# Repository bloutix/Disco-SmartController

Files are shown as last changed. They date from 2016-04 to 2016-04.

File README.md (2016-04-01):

# Disco-SmartController
Arduino based Smart Controller for Dagoma Discovery 200 or Melzi printer with Marlin fw

Version: 1.0b

Prérequis:
	- Arduino MEGA 2560
	- 3.2 " TFT touch
	- TFT LCD MEGA Shield V1.0
	- Un adaptateur BT HC-06 (optionnel)
	- Flash IC (sera une option) mais ne peux fonctionner sans si aucune modification dans le code
	- des cables Dupont

Le contenu du fichier Libraries.zip est à copier dans le dossier librarie de l'ide ARDUINO.

Il vous faut changer le port série dans le fichier configuration du firmware Marlin en SERIAL1.
Attention: le fait de changer le port série empêche de controller l'imprimante depuis l'USB de la Melzi,
mais le controle est possible via l'USB de l'Arduino (115200 bps).

Connection du Smart Controller vers la MELZI:
	- RX (melzi) -> TX1 (Arduino)
	- TX (melzi) -> RX1 (Arduino)
	- GND (melzi) -> GND (Arduino)
	
Connextion du module Bluetooth:
	- RX (BT) -> TX2 (Arduino)
	- TX (BT) -> RX2 (Arduino)
	- GND (BT) -> GND (Arduino)
	- VCC (BT) -> 5V

Les fonctionnalités:
	- Affichage de la température (Hotend + Bed)
	- Réglages température, pas de déplacement (0.1, 1, 10, 100mm)
	- Mise en Pause de l'impression
	- Arret d'urgence
	- Connextion Switch (Controller->Melzi, BT->Melzi, USB->Melzi)
	- Déplacement manuel des axes, Homing, filament
	- Marche / Arrêt du ventilateur
	- Control d'un ou plusieurs SERVO (à améliorer)
	
  Fonctionnalités à venir:
	- Affichage et sélection d'un fichier à imprimer sur la SD
	- Affichage du temps restant, et numéro de couche en cours
	- Envoi manuel de G-code, M-code
	- Réglage du SmartController depuis l'écran (variables, diverses et activation/désactivation de fonctionnalités)
	
Attention!!!
	Le SmartController est en cours de développement et je ne pourrai en aucun cas être tenu responsable d'une mauvaise utilisation,
	ou de la présence de bug indésirable.

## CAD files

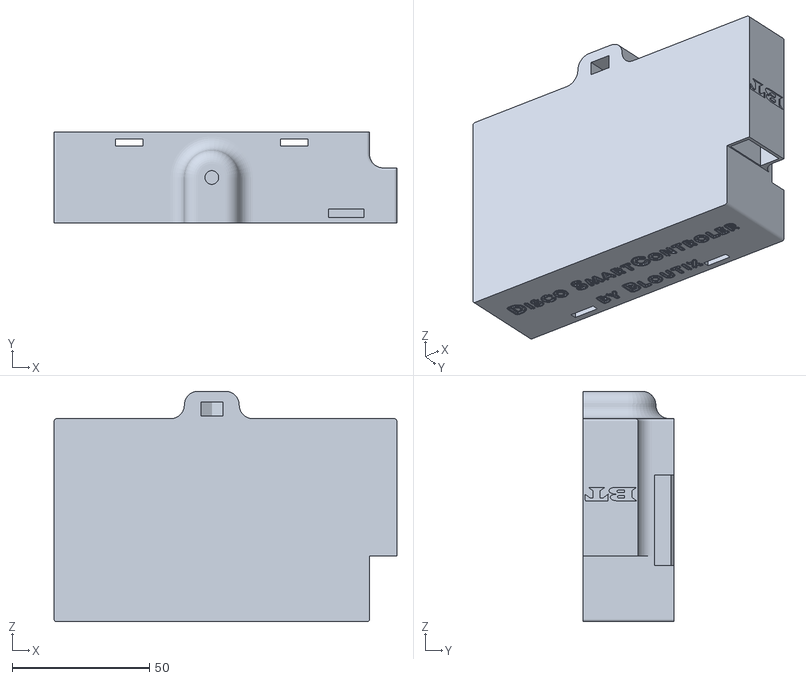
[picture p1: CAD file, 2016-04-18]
STL/Smart Controller Case.STL
125.0 x 33.0 x 84.0

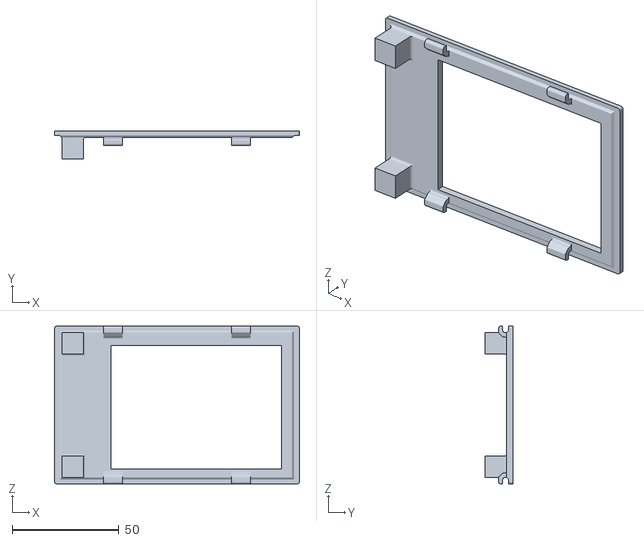
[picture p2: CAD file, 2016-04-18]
STL/Smart Controller Top.STL
115.0 x 13.0 x 74.0

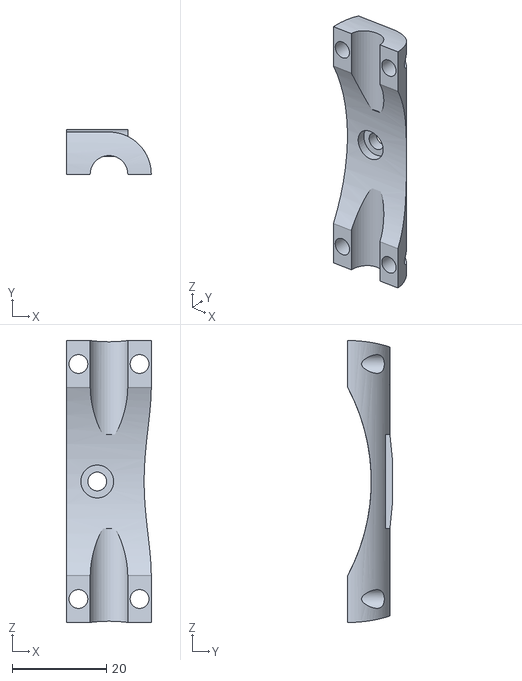
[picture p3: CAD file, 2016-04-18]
STL/mount_top.STL
18.0 x 9.50 x 60.0

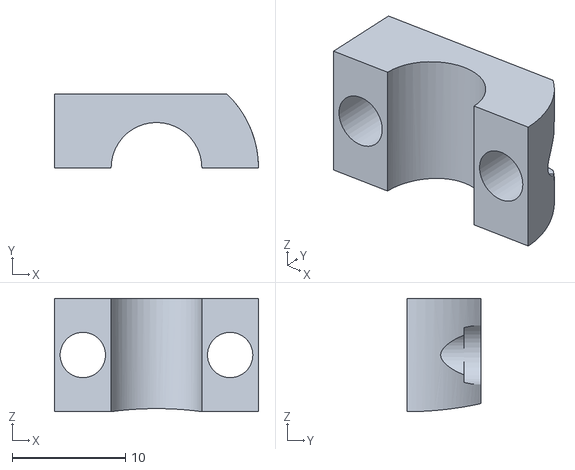
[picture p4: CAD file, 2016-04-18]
STL/mount_bottom.STL
18.0 x 6.50 x 10.0

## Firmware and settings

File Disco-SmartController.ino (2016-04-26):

/*  Disco-SmartController by Bloutix <bloutix@hotmail.fr>
 *   This program is in developement and it was created for Dagoma Discovery 200
 *   
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
 *  Version: 1.0b
 *  Hardware: 
 *  - Arduino MEGA2560, TFT 320QVT or other 3.2 tft touch screen 320x240
 *  - TFT LCD Mega Shield V1.0 moded (added SPI flash memory wire) (will be optionnal)
 *  - Winbond SPI flash IC for storing 
 *  - Bt device: HC-06
 *  - some wire
 */

#include "Arduino.h"
#include <avr/pgmspace.h>
#include <EEPROM.h>

#include <UTFT.h>
#include <UTouch.h>
#include <TFT_ExtensionV2.h>
#include <SPI.h>
#include <SPIflash.h>
#include <UTFT_SPIflash.h>

#include "variables.h" //loading variable setting
#include "FWcode.h"   //gcode command
#include "language.h" //language array

//this is for servo z-probe
/*#include <Servo.h>
Servo Zservo;*/
//bool zstate = false;
void setup(){ 
    //Dont Touch this
  for(int i=0;i<8;i++){  //it take config from EEPROM
    addr[i]=EEPROM.read(i);
    delay(5);
  }
  //Dont touch this
  SERIAL_P.begin(spdVal(addr[0]>>5)); //init printer com dont delete
  SERIAL_U.begin(spdVal(addr[0]>>5));
  SERIAL_P.setTimeout(100);
  SERIAL_U.setTimeout(100);
  
  myFlash.begin();  //images stored in lcd flash ic
 // Zservo.attach(9);
  
  myGLCD.InitLCD();
  myGLCD.clrScr();
  myGLCD.setFont(SmallFont);
  myTouch.InitTouch();
  myTouch.setPrecision(PREC_MEDIUM);

  TCHB.Coords(20,60,68,108);
  BTB.Coords(90,60,138,108);
  USBB.Coords(20,130,68,178);
  SETB.Coords(90,130,138,178);
  TCHB.Colors(GREEN,WHITE,NOFILL,SQUARED);
  BTB.Colors(GREEN,WHITE,NOFILL,SQUARED);
  USBB.Colors(GREEN,WHITE,NOFILL,SQUARED);
  SETB.Colors(GREEN,WHITE,NOFILL,SQUARED);
  BACK.Coords(0,220,20,239);
  BACK.Colors(GREEN,BLACK,NOFILL,SQUARED);
  myGLCD.fillScr(BLACK);
}

void loop() { 
  switch(disp_pg){
    case 0:
      disp_HOM();
    break;
    case 1:
      disp_TCH();
    break;
    case 2:
      disp_BT();
    break;
    case 3:
      disp_USB();
    break;
    case 4:
      disp_SET();
    break;
    case 5:
      disp_SD();
    break;
    case 6:
      disp_Mcode();
    break;
  }
}  
/*void serialEvent(){
  if(!autoUSB){
    loaded = false;
    myGLCD.setColor(BLACK);
    myGLCD.fillRect(0,10,319,239);
    autoUSB = true;
    disp_pg=3;
  }
}
/*void serialEvent1(){
    chkServo();
}
void serialEvent2(){
 if(!autoBT && bitRead(addr[0],1)){
    loaded = false;
    myGLCD.setColor(BLACK);
    myGLCD.fillRect(0,10,319,239);
    autoBT = true;
    disp_pg=2;
 }
}*/
//PAGES d'affichage
void disp_Mcode(){    //afichage du clavier pour envoie de ligne de commande
  if (loaded == false) {
    myGLCD.setColor(BLACK);
    myGLCD.fillRect(0,10,319,220);
    myFiles.loadBitmap(5,0,219);
    myGLCD.setBackColor(BLACK);
    myGLCD.setColor(RED);
    myGLCD.print(str(0),CENTER,15);
    myKB.Colors(WHITE, BLACK, GREY, NOFILL);
    myKB.SetupMobileKB(0,30, 319, 180); //NEEDED TO WORK!
    loaded = true;
  }
  char buf[30] = {'\0'};
  myKB.ReceiveMsg(20, 225, WHITE); // X,Y(position on screen), Color
  if (myKB.Mobile_KeyBoard(buf, BLUE))
  {
    setStateDisplay(buf);
    SERIAL_P.println(buf);
    /*awaitingOK=true;
    while(awaitingOK){
      //checkForOk();
    }*/
  }
  if (BACK.Touch()){
    myGLCD.setColor(BLACK);
    myGLCD.fillRect(0,10,319,239);
    disp_pg =1;
    loaded = false;
  }
}
void disp_HOM(){  //affichage de l'écran d'accueil
  if (loaded == false) {
  myGLCD.setColor(CYAN);
  myGLCD.drawRoundRect(0,224,319,239);
  myGLCD.setColor(BLACK);
  myGLCD.fillRect(0,0,319,10);
  myGLCD.setBackColor(BLACK);
  myGLCD.setColor(CYAN);
  myGLCD.print(str(1),CENTER,0);
  myGLCD.setColor(CYAN);
  myGLCD.print(str(2),CENTER,225);
  BTB.ReDraw();
  TCHB.ReDraw();
  USBB.ReDraw();
  SETB.ReDraw();
  myFiles.loadBitmap(4,160,45); //logo dagoma
  myFiles.loadBitmap(6,90,130); //logo setting
  myFiles.loadBitmap(7,90,60);  //logo usb
  if(bitRead(addr[0],1)){
     myFiles.loadBitmap(8,20,130); //logo bluetooth
  }
  myFiles.loadBitmap(9,20,60);  //logo touchinterface
  loaded = true;
  }

  if (TCHB.Touch()){
    loaded = false;
    myGLCD.setColor(BLACK);
    myGLCD.fillRect(0,10,319,239);
    disp_pg = 1;
  } else if(BTB.Touch() && bitRead(addr[0],1)){
    if(bitRead(addr[0],1)){
      loaded = false;
      myGLCD.setColor(BLACK);
      myGLCD.fillRect(0,10,319,239);
      disp_pg = 2;
    }
  } else if(USBB.Touch()){
    loaded = false;
    myGLCD.setColor(BLACK);
    myGLCD.fillRect(0,10,319,239);
    disp_pg = 3;
  } else if(SETB.Touch()){
    loaded = false;
    myGLCD.setColor(BLACK);
    myGLCD.fillRect(0,10,319,239);
    disp_pg = 4;
  }
}
void disp_TCH(){  //affichage de l'interface de controle tactil
  if (loaded == false) {
  #include "interface.h" //loading customised interface var and function
  myFiles.loadBitmap(5,0,219);
  moveS.Unlock();
  tempB.Unlock();
  tempH.Unlock();
  Print_Bar.Unlock();
  moveS.SetStartingValue(lastMv);
  tempB.SetStartingValue(lastTb);
  tempH.SetStartingValue(lastHb);
  moveS.Draw();
  tempB.Draw();
  tempH.Draw();
  Print_Bar.Draw();
  loaded = true;
  }
    
  InitTouchInterface();
  unsigned long currentMillis = millis();
  if (Bst.Touch()){  //arret urgence
     sendGcode(code(10)); //10->M112 or 11->M410
  }
    if ((currentMillis - lastUpdate) >= 5000) { //affiche la température toute les 5 secondes
      getTemperatures();
      getPrintState();
      lastUpdate=currentMillis; 
    }
  if (BACK.Touch()){
    myGLCD.setBackColor(BLACK);
    myGLCD.setColor(BLACK);
    myGLCD.fillRect(0,10,319,239);
    myGLCD.fillRect(0,0,15,10);
    disp_pg =0;
    loaded = false;
  }
}
void disp_SET(){  //affichage de la fenetre de parametrage
  if (loaded == false) {
        myGLCD.setColor(BLACK);
        myGLCD.fillRect(0,10,319,239);
        myGLCD.setBackColor(BLACK);
        myGLCD.setColor(RED);
        myGLCD.print(str(0),CENTER,15);
        SDPTB.Coords(245,220,319,239);
        SDPTB.Colors(BLACK,FILL,SQUARED);
        myFiles.loadBitmap(5,0,219);//back btn
        sub_loaded = false;
        loaded = true;
      }
  switch (sub_pg){
    case 0: //pge lanques, bt, bed, dago, flash ic
      if (sub_loaded == false) {
          rstBtn(0);
          myGLCD.setColor(WHITE);
          myGLCD.print(str(4),20,40);
          myGLCD.print(str(5),120,40);
          myGLCD.print(str(6),170,40);
          myGLCD.print(str(7),20,70);
          myGLCD.print(str(8),20,100);
          myGLCD.print(str(9),20,130);
          myGLCD.print(str(10),20,160);
        sub_loaded = true;
      }
        myRB.RadioButtons(Chkbox);
        Bt3.Toggle();
        Bt4.Toggle();
        Bt5.Toggle();
        Bt6.Toggle();
        if(SDPTB.Touch()){
          bitWrite(addr[0],0,((Bt1.getState()) ? 0 : 1)); //langue FR/EN
          bitWrite(addr[0],4,((Bt3.getState()) ? 1 : 0)); //Marlin FW Dagoma / !Dagoma
          bitWrite(addr[0],1,((Bt4.getState()) ? 1 : 0)); //Bluetooth
          bitWrite(addr[0],2,((Bt5.getState()) ? 1 : 0)); //BED
          bitWrite(addr[0],3,((Bt6.getState()) ? 1 : 0)); //Flash IC 
        
          myGLCD.setColor(BLACK);
          myGLCD.fillRect(0,30,319,219);
          sub_pg = 1;
          sub_loaded = false;
        } else if (BACK.Touch()){
          myGLCD.setColor(BLACK);
          myGLCD.fillRect(0,10,319,239);
          disp_pg =0;
          sub_loaded = false;
          loaded = false;
        }
    break;
    case 1: //vitesse com, sd files
      if (sub_loaded == false) {
      rstBtn(1);
      myGLCD.setColor(WHITE);
      myGLCD.print(str(11),20,40);
      myGLCD.print(str(12),20,100);
      myGLCD.print(str(13),20,130);
      myGLCD.print(str(14),20,160);
      bps = addr[0]>>5;
      par1 = (addr[1]<<3);
      par1 = par1>>3;
      myGLCD.printNumI(par1,170,100, 0);
      myGLCD.print(String(spdVal(bps),DEC),100,70);
      sub_loaded = true;
      }
    if (Bt1.Touch()){
        delay(30);
      if(bps>1)
        bps--;
    } else if(Bt2.Touch()){
      delay(30);
      if(bps<6)
        bps++;
    } else if(Bt3.Touch()){
      delay(30);
      if(par1 > 1)
        par1--;
    } else if(Bt4.Touch()){
        delay(30);
      if(par1 < 25)
        par1++;
    }
        updispval(par1,170,100, 0);
        updispval(bps,100,70, 1);
        Bt5.Toggle();
        Bt6.Toggle();
        if(SDPTB.Touch()){
      speed2byte(bps);// ecrit comspeed dans le byte 0
      sdf2byte(par1); //ecrit nb sd file dans byte 1
      bitWrite(addr[1],5,((Bt5.getState()) ? 1 : 0)); //TFT SD
      bitWrite(addr[1],7,((Bt6.getState()) ? 1 : 0)); //DUAl EXTRUDER
          myGLCD.setColor(BLACK);
          myGLCD.fillRect(0,30,319,219);
          sub_pg = 2;
          sub_loaded = false;
        } else if (BACK.Touch()){
          myGLCD.setColor(BLACK);
          myGLCD.fillRect(0,30,319,219);
          sub_pg =0;
          sub_loaded = false;
        }
    break;
    case 2: // temp and case sup 255°
      if (sub_loaded == false) {
        rstBtn(2);
        myGLCD.setColor(GREEN);myGLCD.drawRect(20,95,70,115);
        myGLCD.setColor(GREY);myGLCD.drawRect(100,95,150,115);myGLCD.drawRect(180,95,230,115);
        myGLCD.drawRect(20,165,70,185);myGLCD.drawRect(100,165,150,185);myGLCD.drawRect(180,165,230,185);
        myGLCD.setColor(WHITE);
        myGLCD.print(F("Buse > 255$C ?"),20,40);
        myGLCD.print(F("Temperatures de la Buse"),20,70);
        myGLCD.print(F("T1"),40,80);myGLCD.print(F("T2"),120,80);myGLCD.print(F("T3"),200,80);
        myGLCD.print(F("Temperatures du lit chauffant"),20,140);
        myGLCD.print(F("T1"),40,150);myGLCD.print(F("T2"),120,150);myGLCD.print(F("T3"),200,150);
        myGLCD.printNumI(addr[2]*mult,30,100);myGLCD.printNumI(addr[3]*mult,110,100);myGLCD.printNumI(addr[4]*mult,190,100);
        myGLCD.printNumI(addr[5],30,170);myGLCD.printNumI(addr[6],110,170);myGLCD.printNumI(addr[7],190,170);
        sub_loaded = true;
      }

        (Bt1.Toggle())? bitWrite(addr[1],6,1):bitWrite(addr[1],6,0);
        mult=(Bt1.getState())? 2:1;
         myGLCD.setColor(WHITE);
         myGLCD.printNumI(addr[2]*mult,30,100);myGLCD.printNumI(addr[3]*mult,110,100);myGLCD.printNumI(addr[4]*mult,190,100);
         
        if(Bt4.Touch()){
          myGLCD.setColor(GREY);
          myGLCD.drawRect(((selected-col)*80)+20,95+ln,((selected-col)*80)+70,115+ln);
          selected--;
          col = (selected>2)? 3: 0;
          ln = (selected>2)? 70:0;
          if(selected<0){selected=0;}
          myGLCD.setColor(GREEN);
          myGLCD.drawRect(((selected-col)*80)+20,95+ln,((selected-col)*80)+70,115+ln);
          delay(70);
        }else if(Bt5.Touch()){ 
          myGLCD.setColor(GREY);
          myGLCD.drawRect(((selected-col)*80)+20,95+ln,((selected-col)*80)+70,115+ln);
          selected++;
          col = (selected>2)? 3: 0;
          ln = (selected>2)? 70:0;
          if(selected>param_cnt){selected=param_cnt;}
          myGLCD.setColor(GREEN);
          myGLCD.drawRect(((selected-col)*80)+20,95+ln,((selected-col)*80)+70,115+ln);
          delay(70);
        }else if(Bt2.Touch()){
          updTemp(selected,0);
        }else if(Bt3.Touch()){
          updTemp(selected,1);
        }
        if(SDPTB.Touch()){
          myGLCD.setColor(BLACK);
          myGLCD.fillRect(0,30,319,219);
          selected=0;
          sub_pg = 3;
          sub_loaded = false;
        } else if (BACK.Touch()){
          myGLCD.setColor(BLACK);
          myGLCD.fillRect(0,30,319,219);
          selected=0;
          sub_pg =1;
          sub_loaded = false;
        }
    break;
    case 3: //resume and validate
      if (sub_loaded == false) {
        myGLCD.setColor(BLACK);
        SDPTB.Text(strc(18),RED,Small);
        SDPTB.ReDraw();
        resConf();
        sub_loaded = true;
      }
        if(SDPTB.Touch()){
          myGLCD.setColor(BLACK);
          myGLCD.fillRect(0,30,319,219);
          sub_pg = 4;
          sub_loaded = false;
        } else if (BACK.Touch()){
          myGLCD.setColor(BLACK);
          myGLCD.fillRect(0,30,319,219);
          SDPTB.Text(strc(19),BLUE,Small);
          SDPTB.ReDraw();
          sub_pg =2;
          sub_loaded = false;
        }
    break;
    case 4: //do eeprom update
      if (sub_loaded == false) {
        SDPTB.Text(strc(20),WHITE,Small);
        SDPTB.ReDraw();
        myGLCD.setColor(WHITE);
        myGLCD.print(str(21),CENTER,115);
        myGLCD.setColor(BLACK);
        myGLCD.fillRect(0,220,30,239);
        //putConf(); //sauvegarde les parametre dans eeprom
        
        
        sub_loaded = true;
      }
      if (SDPTB.Touch()){
          myGLCD.setColor(BLACK);
          myGLCD.fillRect(0,10,319,239);
          SDPTB.Text("",WHITE,Small);
          sub_pg =0;
          disp_pg = 0;
          sub_loaded = false;
          loaded = false;
        }
    break;
  }
}
void disp_USB(){  //affichage de la fenetre de communication usb
  if (loaded == false) {
  //SERIAL_U.begin(spdVal(addr[0]>>5)); // init usb to printer

  myFiles.loadBitmap(2,0,0);
  myFiles.loadBitmap(5,0,219);
  myGLCD.setColor(RED);
  myGLCD.drawRoundRect(50,105,270,125);
  myGLCD.setBackColor(BLACK);
  myGLCD.print(str(22),CENTER,110);
  loaded =true;
  }
  
  if (BACK.Touch()){
    SERIAL_U.flush();
    delay(2);
    SERIAL_U.read();
    //SERIAL_U.end();
    myGLCD.setBackColor(BLACK);
    myGLCD.setColor(BLACK);
    myGLCD.fillRect(0,10,319,239);
    myGLCD.fillRect(0,0,15,10);
    disp_pg =0;
    autoUSB=false;
    loaded = false;
  } else {
    serialEcho(1);
  }
}
void disp_BT(){   //affichage de la fenetre de communication bluetooth
  if (loaded == false) {
  myFiles.loadBitmap(3,0,0);
  myFiles.loadBitmap(5,0,219);
  myGLCD.setColor(BLUE);
  myGLCD.drawRoundRect(50,105,270,125);
  myGLCD.setBackColor(BLACK);
  SERIAL_BT.begin(spdVal(addr[0]>>5)); //init bt to printer
  SERIAL_BT.setTimeout(100);

  myGLCD.print(str(23),CENTER,110);
  loaded =true;
  }
  
  if (BACK.Touch()){
    SERIAL_BT.flush();
    delay(2);
    SERIAL_BT.read();
    SERIAL_BT.end();
    myGLCD.setBackColor(BLACK);
    myGLCD.setColor(BLACK);
    myGLCD.fillRect(0,10,319,239);
    myGLCD.fillRect(0,0,15,10);
    disp_pg =0;
    autoBT=false;
    loaded = false;
  } else {
    if(bitRead(addr[0],1)){
      serialEcho(2);
    }
  }
}
void disp_SD(){   //affichage de la liste des fichiers sur la carte sd
  if (loaded == false) {
  myFiles.loadBitmap(5,0,219);
  myGLCD.setBackColor(GREY);
  myGLCD.setColor(BLUE);
  myGLCD.print(str(24),CENTER,15);
  PSdFilelist();
  SDPTB.Coords(220,180,300,210);
  SDPTB.Colors(CYAN,GREEN,FILL,SQUARED);
  SDPTB.ReDraw();
  UPB.Coords(260,50,300,90);
  UPB.Colors(GREEN,RED,FILL,SQUARED);
  UPB.ReDraw();
  DNB.Coords(260,110,300,150);
  DNB.Colors(GREEN,BLUE,FILL,SQUARED);
  DNB.ReDraw();
  myGLCD.setColor(BLUE);
  myGLCD.print(str(18),230,190);
  for (int i=0; i<file_cnt; i++){
    if(i==0){
      myGLCD.setColor(GREEN);
      myGLCD.drawRect(45,(i*20)+38,190,(i*20)+52);
    }
    myGLCD.setBackColor(GREY);
    myGLCD.setColor(WHITE);
    myGLCD.print(file[i],50,(i*20)+40);
  }
  selected = 0;
  loaded =true;
  }
  if(DNB.Touch()){
    if(selected<file_cnt-1){
    myGLCD.setColor(GREY);
    myGLCD.drawRect(45,(selected*20)+38,190,(selected*20)+52);
    selected++;
    myGLCD.setColor(GREEN);
    myGLCD.drawRect(45,(selected*20)+38,190,(selected*20)+52);
    delay(50);
    }
  }else if(UPB.Touch()) {
    if(selected>0){
    myGLCD.setColor(GREY);
    myGLCD.drawRect(45,(selected*20)+38,190,(selected*20)+52);
    selected--;
    myGLCD.setColor(GREEN);
    myGLCD.drawRect(45,(selected*20)+38,190,(selected*20)+52);
    delay(50);
    }
  }else if(SDPTB.Touch()){
    file[selected].toLowerCase();
    SERIAL_P.println(code(2)+file[selected]);
    memset(file,0,sizeof(file));
    myGLCD.setBackColor(BLACK);
    myGLCD.setColor(BLACK);
    myGLCD.fillRect(0,10,319,239);
    myGLCD.fillRect(0,0,15,10);
    disp_pg=1;
    loaded = false;
    waitPrinting = true;
  }
  if (BACK.Touch()){
    myGLCD.setBackColor(BLACK);
    myGLCD.setColor(BLACK);
    myGLCD.fillRect(0,10,319,239);
    myGLCD.fillRect(0,0,15,10);
    disp_pg =1;
    loaded = false;
  }
}
void disp_PopUp(byte i){ //pop up de reglage
  switch (i){
    case 0:     //hotend
    break;
    case 1:     //heatbed
    break;
    case 2:     //MV speed
    break;
  }
}
/*Fonctions principales*/
/*void chkServo(){
   if (SERIAL_P.readStringUntil('\n')== F("zservo")){
    if(zstate==false){
      //Zservo.attach(9);
      Zservo.write(90);  //down pos
      delay(500);
      //Zservo.detach();
      zstate = true;
    } else if (zstate==true)  {
      //Zservo.attach(9);
      Zservo.write(150);  //up pos
      delay(500);
      //Zservo.detach();
      zstate=false;
    }
  }
}*/
//fonctions liées au SLIDER
void setMvStep(unsigned int MvStep){ //fonction de parametrage des mouvements en mm
  if (MvStep == 1){
    mvsval = 0.1;
  } else if (MvStep == 2){
    mvsval = 1;
  } else if (MvStep == 3){
    mvsval = 10;
  } else {
    mvsval = 100;
  }
    strMvc = dtostrf(mvsval,3,1,strcMv);
    myGLCD.setColor(BLACK);
    myGLCD.fillRect(140,209,195,219);
    myGLCD.setBackColor(BLACK);
    myGLCD.setColor(GREEN);
    myGLCD.print(str(37),140,195);
    myGLCD.print(strMvc+str(38),140,208);
}
void setBedTemp(unsigned int temp){  //fonction de parametrage de la température du lit chauffant
  if (temp == 1){
    sendGcode(code(17)+"0");
  } else if (temp == 2){
    sendGcode(code(17)+String(addr[5],DEC));
  } else if (temp == 3){
    sendGcode(code(17)+String(addr[6],DEC));
  } else {
    sendGcode(code(17)+String(addr[7],DEC));
  }
}
void setHdTemp(unsigned int temp){   //fonction de parametrage de la température de la buse
    if (temp == 1){
    sendGcode(code(12)+"0");
  } else if (temp == 2){
    sendGcode(code(12)+String(addr[2],DEC));
  } else if (temp == 3){
    sendGcode(code(12)+String(addr[3],DEC));
  } else {
    sendGcode(code(12)+String(addr[4],DEC));
  }
}

//fonctions de communication
void serialEcho(byte scom){ //bypass serial com
  if (scom==1){
    if (SERIAL_U.available() > 0) {
      SERIAL_P.write(SERIAL_U.read());
    }
    if (SERIAL_P.available() > 0) {
      SERIAL_U.write(SERIAL_P.read());
    }
  } else if (scom==2){
    if (SERIAL_BT.available() > 0) {
      SERIAL_P.write(SERIAL_BT.read());
    }
    if (SERIAL_P.available() > 0) {
      SERIAL_BT.write(SERIAL_P.read());
    }
  }
}
void sendGcode(String lineOfCode){    //envoie de Gcode avec attente de msg OK
  SERIAL_P.println(lineOfCode);
  //awaitingOK = true;  
  setStateDisplay(lineOfCode);
  delay(1);
  //checkForOk();
}
/*void checkForOk() {   //fonction d'attente de MSG_OK
  String c ="";
   while (SERIAL_P.available()) {  
    c= SERIAL_P.readString();
    if (c.startsWith(F("ok"))) {awaitingOK=false;}
    else{ awaitingOK=false; }
    c="";
    delay(1);     
    }
}*/
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

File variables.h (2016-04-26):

/*  Disco-SmartController by Bloutix <bloutix@hotmail.fr>
 *   This program is in developement and it was created for Dagoma Discovery 200
 *   
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
 *  Version: 1.0b
 *  Hardware: 
 *  - Arduino MEGA2560, TFT 320QVT or other 3.2 tft touch screen 320x240
 *  - TFT LCD Mega Shield V1.0 moded (added SPI flash memory wire) (will be optionnal)
 *  - Winbond SPI flash IC for storing 
 *  - Bt device: HC-06
 *  - some wire
 */
 
//all pre-setup variables
//#define imagedatatype  unsigned short
extern uint8_t SmallFont[];
UTFT myGLCD(ITDB32S,38,39,40,41);
UTouch  myTouch(6,5,4,3,2);
SPIflash      myFlash(45);//45
UTFT_SPIflash myFiles(&myGLCD,&myFlash);

// Not touch is for TFT_extensionV2 button lib
Base B(&myGLCD,&myTouch); // Base class, NEEDED!!!

//keyboard
MobileKeyboard myKB(&B);

//initialize slider
Slider moveS(&B,VERTICAL);
Slider tempH(&B,VERTICAL);
Slider tempB(&B,VERTICAL);

Meter Print_Bar(&B,VERTICAL);

//btn for setting
Box Bt1(&B),Bt2(&B),Bt3(&B),Bt4(&B),Bt5(&B),Bt6(&B);
Box * Chkbox[] = {&Bt1, &Bt2};
Radio myRB;

//dont touch this bloc
//var for setting
byte addr[8] = {B11011110,B00000101,185,210,230,60,90,110}; //dont touch this
byte par1 =1;
byte bps = 1;
bool chg[2] = {false, false};
unsigned int lval[2] = {0,0};
unsigned int param_cnt=5;
unsigned int ln = 0;
unsigned int col = 0;
unsigned int mult = 1;  
//dont touch this bloc

#define SERIAL_U Serial
#define SERIAL_P Serial1   //port serie smartcontroller -> printer
#define SERIAL_BT Serial2   //port serie smartcontroller -> bt module
//#define BAUDRATE 115200
bool autoBT = false;
bool autoUSB = false;
bool waitPrinting=false;
bool isSDPrinting=false;
//pas encore implemente sécurité en cas de coupure électrique ou autre incident
unsigned long lastByte = 0;

byte disp_pg =0;
byte sub_pg = 0;
unsigned long lastUpdate = 0;
bool awaitingOK = false;
bool initcom = true;
bool fanS = true;
bool Brked = false;
bool loaded = false;
bool sub_loaded = false;

//this is for SD file list
unsigned int file_cnt = 0;
String file[]= {"","","","","","","","","","","","","","","","","","","","","","","","",""};
unsigned int selected = 0;

char strcMv[15];
float mvsval = 0.1; //desired mv step
String strMvc = "0.1";

//var of slide control
unsigned int lastTb,lastHb,lastMv;

//define home button
Box TCHB(&B), BTB(&B), USBB(&B), SETB(&B), BACK(&B), SDPTB(&B);
//define all custom button
Box XH(&B), YH(&B), ZH(&B), UB(&B), DB(&B), LB(&B), RB(&B), UZ(&B), DZ(&B);
Box Eext(&B), Rext(&B), Fan(&B), Bsd(&B), Bpr(&B), Brk(&B), Bst(&B);
Box Bmc(&B),UPB(&B),DNB(&B);

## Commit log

2016-04-01 Update README.MD and Comment not working function in code Put libraries files in archive
    [Disco-SmartController.ino, variables.h]
2016-04-03 Added functionnality: - New home menu - Fully functionnal SD Filelist - added sfd file for import picture in FlashIC Functionnality pended: - Check Printer connection - Display current temp
2016-04-06 Update setting system
    New improved system for storing parameters
    will use only 8 bytes to store all setting such as:
    - Language, bluetooth module, hotbed, flash ic, is dagoma, com. speed
    - Nb of SD files to be show, Use TFT SD, Dual hotend, preseted temp for bed and hotend,
    - bool if hotemp temp must reach over 255°
    This is in dev not fully working at now
2016-04-10 Added and improved - USB auto connexion - fully functionnal setting system - Display printing time - Display printing percentage - keyboard for manual code to send - updated libraries
2016-04-18 - Improved function - removed estimated time - reversed Y axis - implementation of language and Gcode - improved interface response - reworked file
    [Disco-SmartController.ino, variables.h]
2016-04-18 - Added STL file for printing enclosure and mount support
    [Smart Controller Case.STL, Smart Controller Top.STL, mount_bottom.STL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]
2016-04-24 - Fixing small issue with move speed
    [Disco-SmartController.ino]
2016-04-24 - Bug fix displaying symbole ° for degree - Removed all SERIAL_P.read() this slowing the controller
    [Disco-SmartController.ino]
2016-04-24 fixed sd file list selection display issue
    [Disco-SmartController.ino]

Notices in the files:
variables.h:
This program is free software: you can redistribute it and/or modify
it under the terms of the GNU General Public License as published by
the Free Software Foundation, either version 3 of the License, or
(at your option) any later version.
